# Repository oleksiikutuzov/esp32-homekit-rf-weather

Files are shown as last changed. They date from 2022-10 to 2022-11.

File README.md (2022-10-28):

# esp32-homekit-rf-weather

   

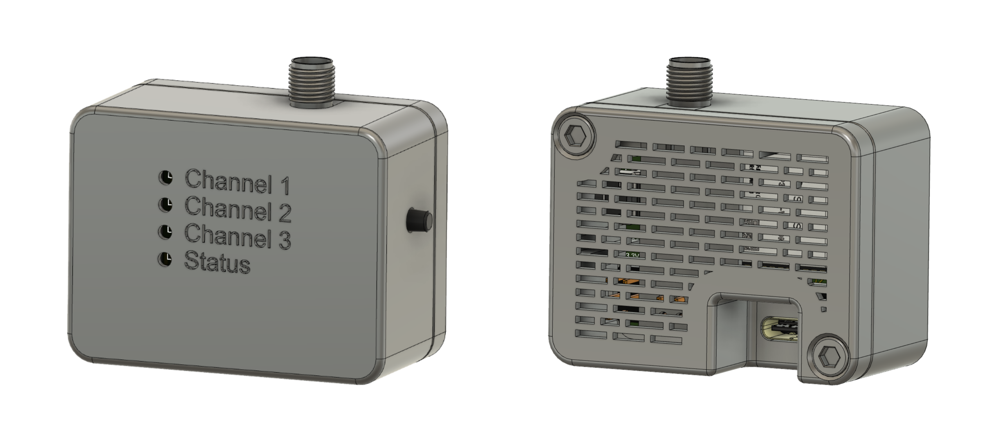
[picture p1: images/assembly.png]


The software is based on [HomeSpan](https://github.com/HomeSpan/HomeSpan) and [RTL_433_ESP](https://github.com/NorthernMan54/rtl_433_ESP) libraries.

> **Warning**
> Don't expect any warranties. I am just a hobbyist, not a professional. It works for me, but you take your own risk using it. I am not liable for any damage to your devices.

## Hardware requirements

1. [Custom PCB](https://github.com/oleksiikutuzov/esp32-homekit-rf-weather/tree/main/PCB) (BOM inside) from this project 
   
   or 
   
   any ESP32 Dev board e.g. [ESP32-DevKitC V4 board](https://docs.espressif.com/projects/esp-idf/en/latest/esp32/hw-reference/esp32/get-started-devkitc.html)
2. [E07-M1101D](https://manuals.plus/ebyte/e07-m1101d-sma-cc1101-433mhz-dip-wireless-module-manual#axzz7j0rVAbnv) 433 MHz Wireless module 

## Pinout

### Wireless module pins

If you are using a dev board, you will need to connect the wireless module to some specific pins of ESP32.

```
ESP32          Module
---------------------
GPIO18         SCK
GPIO19         MISO
GPIO23         MOSI
GPIO5          CS
GPIO22         GDO0
GPIO4          GDO2
```

### LEDs and control button pins

If you are using a dev board, you can utilize any pins you want or not use them at all. There is a control button to be able to reset the device, WIFI or HomeKit configuration. The status pin shows the current state of the device. More info on the status LED and control button is in [HomeSpan User](https://github.com/HomeSpan/HomeSpan/blob/master/docs/UserGuide.md) Guide](https://github.com/HomeSpan/HomeSpan/blob/master/docs/UserGuide.md). Three additional LEDs are blinking on the received signal on any of the channels. To redefine the pins for the dev board edit the following in the sketch:
```C++
#ifdef DEV_BOARD
	#define LED_CH1    13
	#define LED_CH2    21
	#define LED_CH3    17
	#define LED_STATUS 16
	#define BUTTON_PIN 15
```

## How to setup and install

1. Install [PlatformIO Core](https://platformio.org/install/cli) and [VSCode Plugin](https://docs.platformio.org/page/ide/vscode.html) (setup I am using and tested the instructions on) or [PlatformIO IDE](https://platformio.org/install/ide) with built-in Core.
2. Clone this repository
In the `platformio.ini` file set the default environment to `esp32_dev_board` or `esp32_custom_pcb` depending on the board you are using.
   ```
   [platformio]
   default_envs = esp32_custom_pcb
   ```
4. Build the firmware with a dedicated button in the PlatformIO extension or with the command 
   ```
   pio run
   ```
5. Upload the firmware with a dedicated button in the PlatformIO extension or with the command 
   ```
   pio run --target upload
   ```
6. You can monitor the serial output to check everything is working as intended with a dedicated button in the PlatformIO extension or with the command
   ```
   pio run --target monitor
   ```

## Custom Hardware

Custom PCB is designed for the project. Currently for regular ESP32 boards.

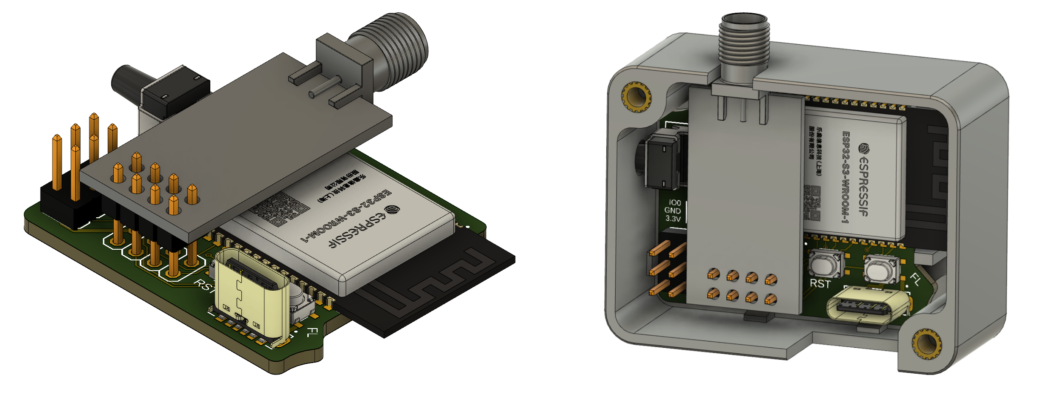
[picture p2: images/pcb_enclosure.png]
render


## Connect to HomeKit

1. Plug your LED Controller to power
2. The access point should start automatically. 
> **Note**
> Later you can manually enter configuration mode (More on [HomeSpan User Guide](https://github.com/HomeSpan/HomeSpan/blob/master/docs/UserGuide.md))
3. Go to WiFi settings on your iPhone/iPad and connect to the "HomeSpan-Setup" WiFi network
4. You will choose your WiFi network and set the setup code for the accessory
5. Go to your Home app and select "Add Accessory"
6. Select "More Options" and you should see your RF Weather Bridge there
## Settings and controls

When adding to HomeKit it will add the unsupported device called **RF Weather Bridge Settings** with device settings (3rd party apps like Eve support this and can be used for configuration). Available custom characteristics:
1. Toggle whether to blink the LEDs on receive
2. Showing the IP address the device is connected to
Set the number of channels, on which you want to receive (created an accessory for each channel). Can be set as 1 to 3
4. Toggle to reboot the device (to reload the device if you change the number of channels)

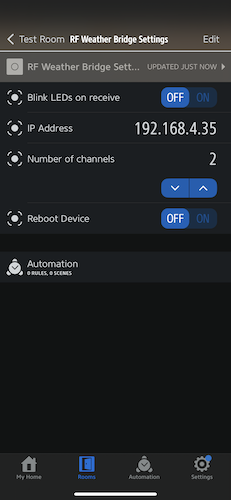
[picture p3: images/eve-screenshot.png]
eve screenshot


The device will throw a Status Fault in Eve app if there are no sensor updates for 5 minutes. 

Characteristics values are saved to NVS, so they will be restored if the device loses power. 

The web server update was implemented. You can flash binary at `http://[DEVICE IP]/update`.
There is a reboot link. Opening `http://[DEVICE IP]/reboot` will force the device to reboot. 

The device can also be controlled by the button on the board. More on [HomeSpan User Guide](https://github.com/HomeSpan/HomeSpan/blob/master/docs/UserGuide.md)

## TODO
### PCB:
- [ ] Add a USB-to-Serial converter to the board
- [ ] Make more space for flashing pin headers

## References and sources

- @HomeSpan for ESP32 HomeKit firmware [GitHub link](https://github.com/HomeSpan/HomeSpan)
- @NorthernMan54 for rtl_433_ESP library [GitHub link](https://github.com/NorthernMan54/rtl_433_ESP)

Although already forbidden by the sources and subsequent licensing, it is not allowed to use or distribute this software for commercial purposes.<br/><br/>

 

###### HomeKit Accessory Protocol (HAP) is Apple’s proprietary protocol that enables third-party accessories in the home (e.g., lights, thermostats and door locks) and Apple products to communicate with each other. HAP supports two transports, IP and Bluetooth LE. The information provided in the HomeKit Accessory Protocol Specification (Non-Commercial Version) describes how to implement HAP in an accessory that you create for non-commercial use and that will not be distributed or sold.

###### The HomeKit Accessory Protocol Specification (Non-Commercial Version) can be downloaded from the [HomeKit Apple Developer page.](https://developer.apple.com/homekit/)

###### Copyright © 2019 Apple Inc. All rights reserved.

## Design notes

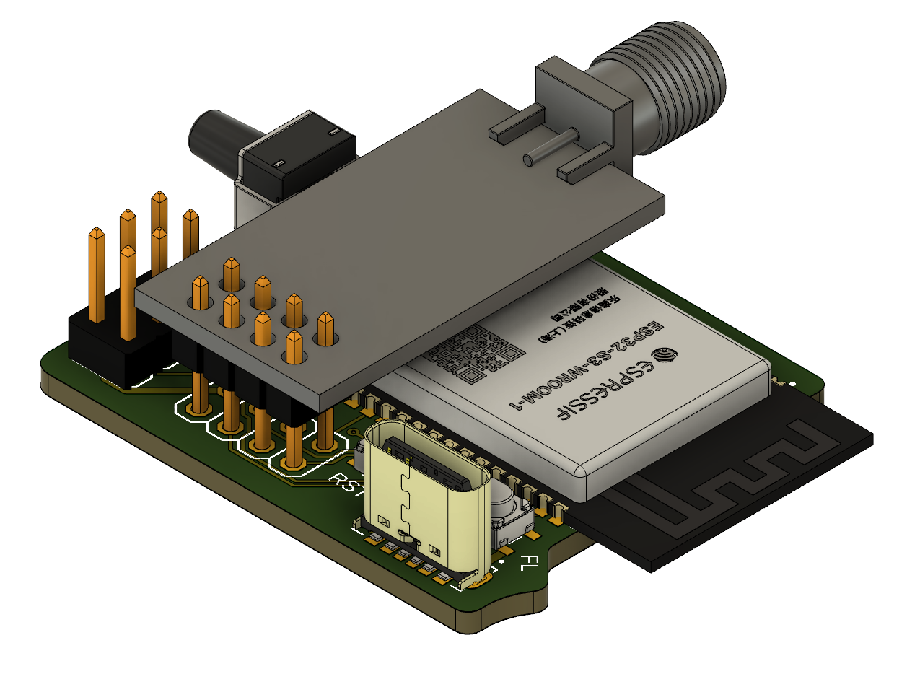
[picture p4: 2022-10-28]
images/pcb.png

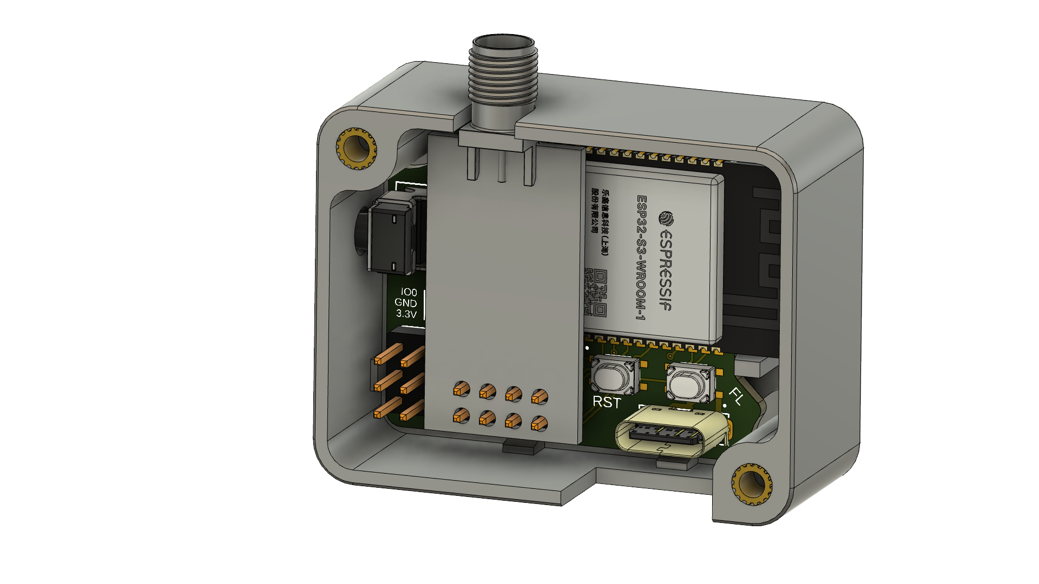
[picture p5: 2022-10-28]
images/enclosure_back.png

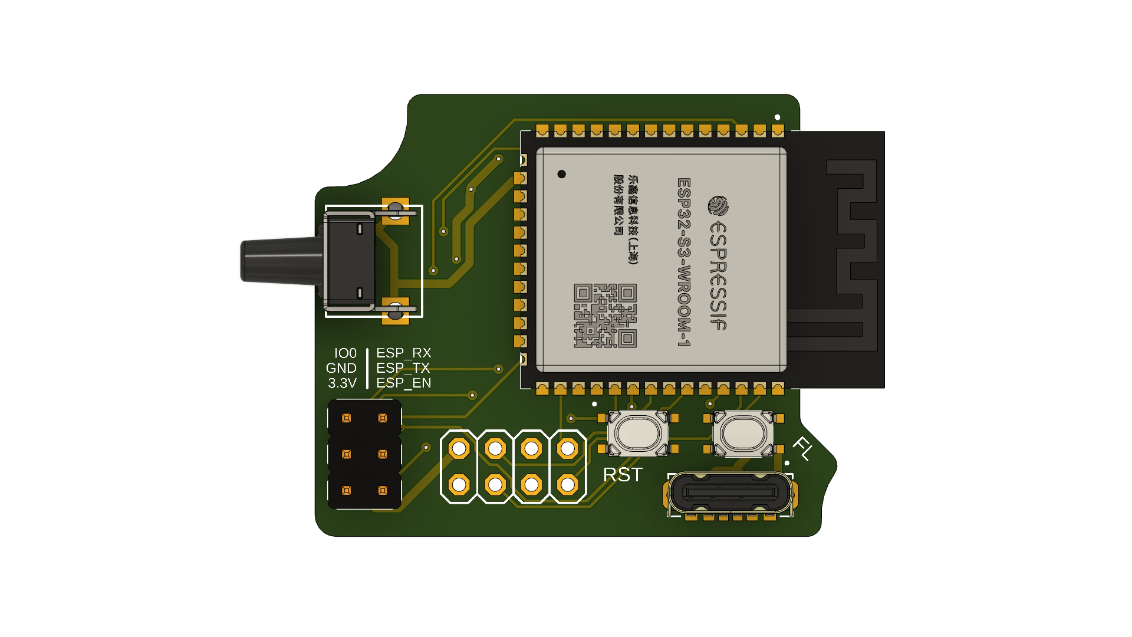
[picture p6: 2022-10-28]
PCB/PCB_TOP.png

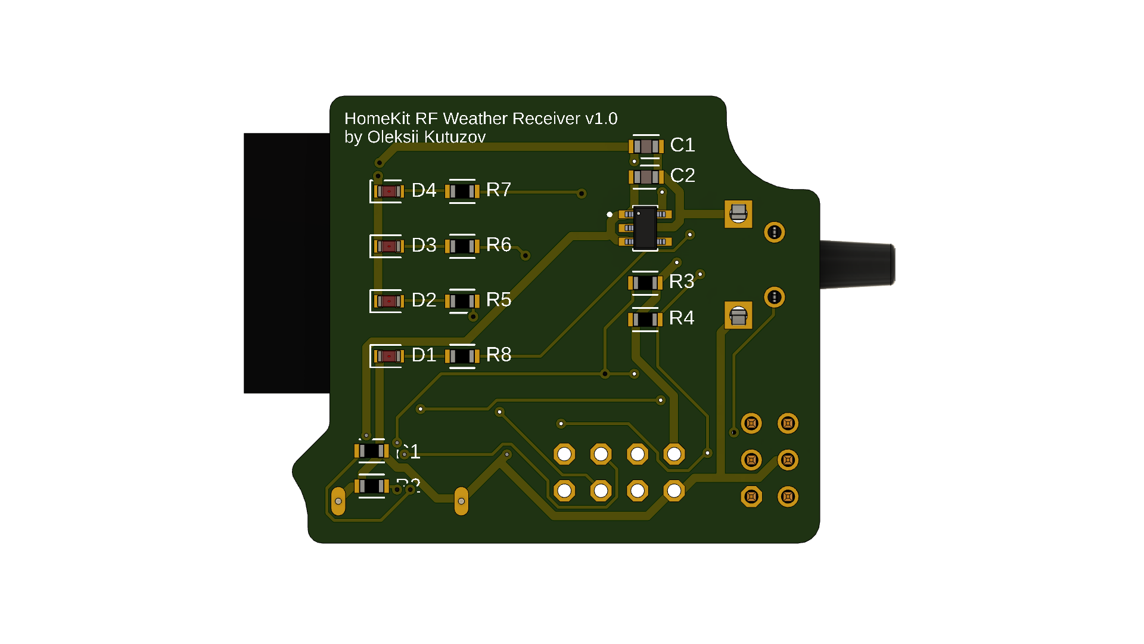
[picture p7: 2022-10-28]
PCB/PCB_BOTTOM.png

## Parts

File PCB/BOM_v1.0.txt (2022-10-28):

Partlist exported from /var/folders/tq/b2m_bkf11ld61j4hqq2g93cr0000gn/T/Neutron/ElectronFileOutput/48587/sch-562322ec-a9bd-47c2-8610-2d14c827d28f/Schematic v1.0 v14.sch at 28.10.22 16:01

Part Value                   Device                   Package                    Description                                                                 
C1   10uF                    C_CHIP-0603(1608-METRIC) CAPC1608X85                Capacitor - Generic                                                         
C2   10uF                    C_CHIP-0603(1608-METRIC) CAPC1608X85                Capacitor - Generic                                                         
D1   LED                     CHIP-FLAT-R_0603-0.80MM  LEDC1608X80N_FLAT-R                                                                                    
D2   LED                     CHIP-FLAT-R_0603-0.80MM  LEDC1608X80N_FLAT-R                                                                                    
D3   LED                     CHIP-FLAT-R_0603-0.80MM  LEDC1608X80N_FLAT-R                                                                                    
D4   LED                     CHIP-FLAT-R_0603-0.80MM  LEDC1608X80N_FLAT-R                                                                                    
J1   USB4125-GF-A_REVA       UJC-VP-3-SMT-TR          CUI_UJC-VP-3-SMT-TR        USB Receptacle                                                              
J3   ESPFLASH-2X3-2.54-PLAIN ESPFLASH-2X3-2.54-PLAIN  2X3-2.54-PLAIN             ESPFlash                                                                    
JP1  PINHD-2X4               PINHD-2X4                2X04                       PIN HEADER                                                                  
R1   5.1k                    R_CHIP-0603(1608-METRIC) RESC1608X60                Resistor Fixed - Generic                                                    
R2   5.1k                    R_CHIP-0603(1608-METRIC) RESC1608X60                Resistor Fixed - Generic                                                    
R3   4.7K                    R_CHIP-0603(1608-METRIC) RESC1608X60                Resistor Fixed - Generic                                                    
R4   4.7K                    R_CHIP-0603(1608-METRIC) RESC1608X60                Resistor Fixed - Generic                                                    
R5   430                     R_CHIP-0603(1608-METRIC) RESC1608X60                Resistor Fixed - Generic                                                    
R6   430                     R_CHIP-0603(1608-METRIC) RESC1608X60                Resistor Fixed - Generic                                                    
R7   430                     R_CHIP-0603(1608-METRIC) RESC1608X60                Resistor Fixed - Generic                                                    
R8   430                     R_CHIP-0603(1608-METRIC) RESC1608X60                Resistor Fixed - Generic                                                    
S1   SKRPACE010              SKRPACE010               SW_SKRPACE010              Switch Tactile N.O. SPST Button J-Bend 0.05A 16VDC 2.55N SMD Automotive T/R 
S2   SKRPACE010              SKRPACE010               SW_SKRPACE010              Switch Tactile N.O. SPST Button J-Bend 0.05A 16VDC 2.55N SMD Automotive T/R 
U$1  MOMENTARY-SWITCH        MOMENTARY-SWITCH         SWITCH-MOMENTARY                                                                                       
U1   AP2112K-3.3TRG1         AP2112K-3.3TRG1          SOT95P285X140-5N           AP2112 Series 0.6 A 3.3 V Fixed Output SMT LDO Linear Regulator - SOT23-5   
U2   ESP32-WROOM-32(8MB)     ESP32-WROOM-32(8MB)      MODULE_ESP32-WROOM-32(8MB) WIFI MODULE 64 MBITS SPI FLASH

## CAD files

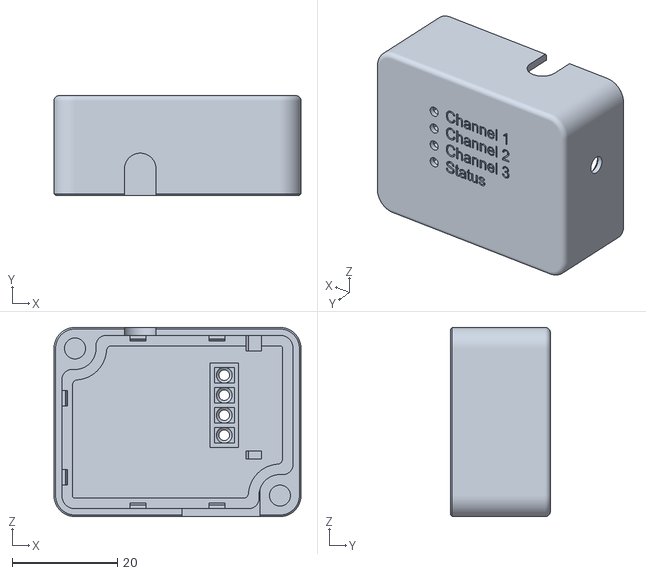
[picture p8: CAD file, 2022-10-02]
STL/Enclosure Front v27.stl
47.0 x 19.0 x 36.0

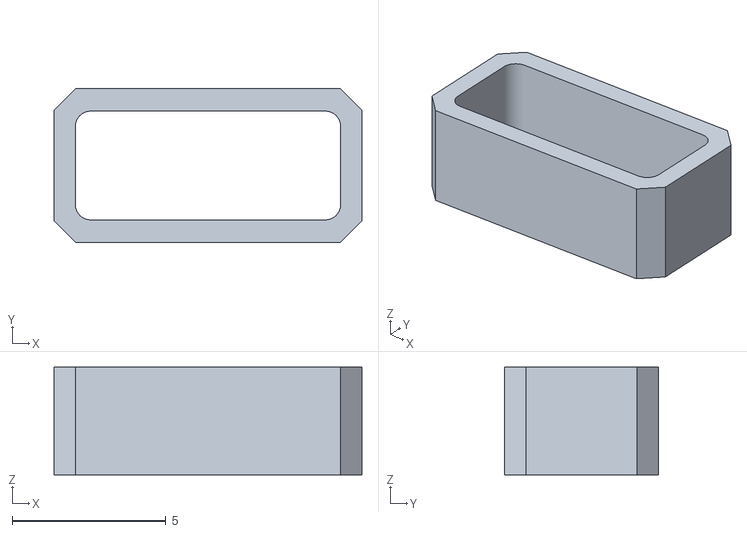
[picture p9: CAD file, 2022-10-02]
STL/Header Spacer v2.stl
10.0 x 5.00 x 3.50

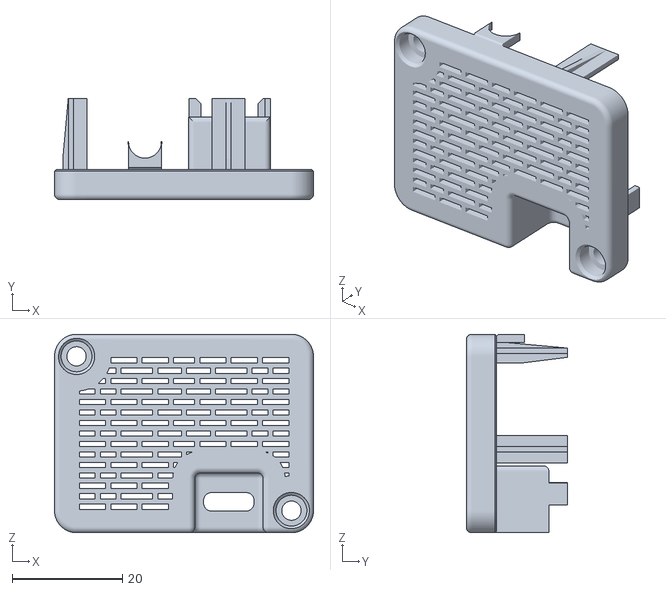
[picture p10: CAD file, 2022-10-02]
STL/Enclosure Back v22.stl
47.0 x 18.4 x 36.0

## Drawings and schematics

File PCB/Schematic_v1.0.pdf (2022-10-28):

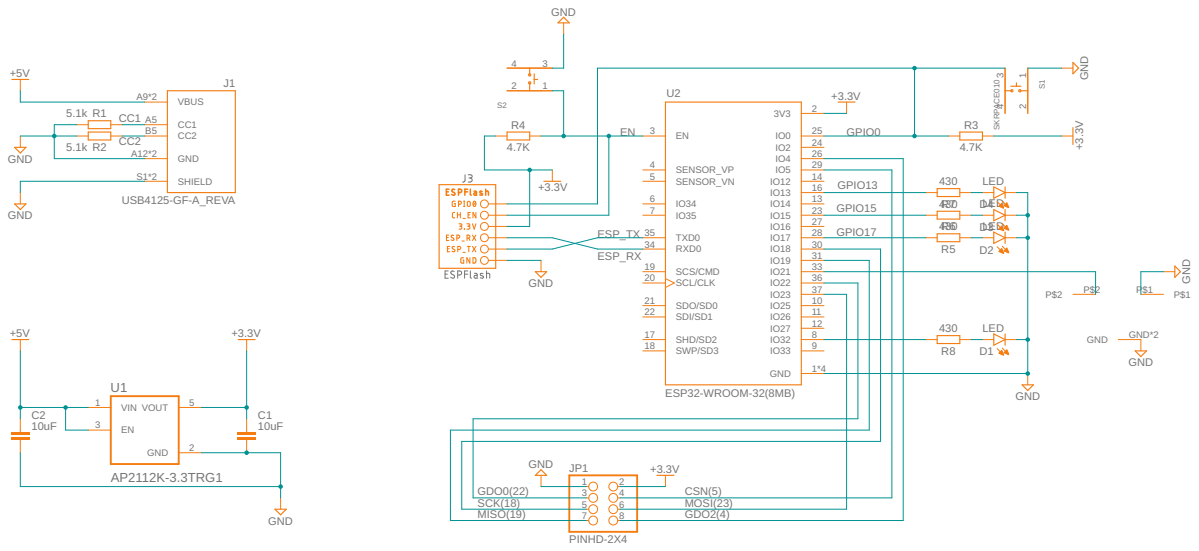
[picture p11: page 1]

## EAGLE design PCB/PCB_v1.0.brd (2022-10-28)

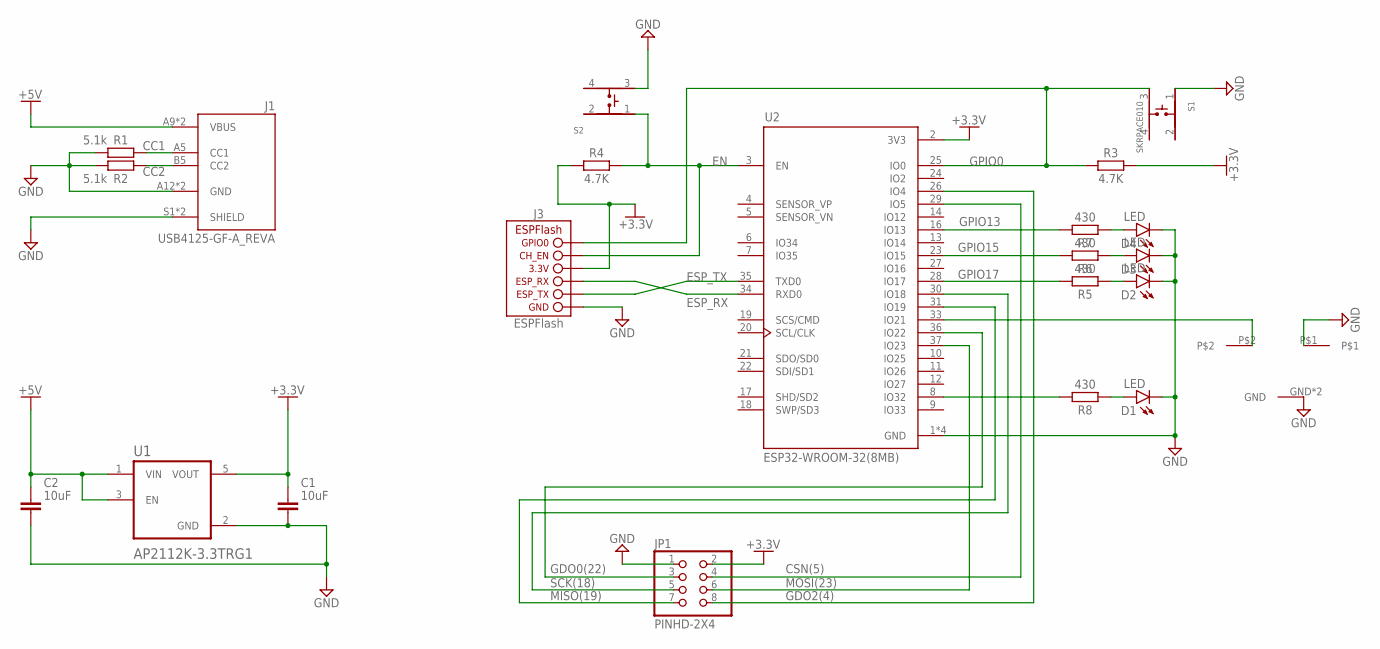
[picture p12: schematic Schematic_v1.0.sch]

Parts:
C1, C2: 10uF; CAPC1608X85
D1, D2, D3, D4: LED; LEDC1608X80N_FLAT-R
J1: USB4125-GF-A_REVA; CUI_UJC-VP-3-SMT-TR
J3: ESPFLASH-2X3-2.54-PLAIN; 2X3-2.54-PLAIN
JP1: PINHD-2X4; 2X04
R1, R2: 5.1k; RESC1608X60
R3, R4: 4.7K; RESC1608X60
R5, R6, R7, R8: 430; RESC1608X60
S1, S2: SKRPACE010; SW_SKRPACE010
U1: AP2112K-3.3TRG1; SOT95P285X140-5N
U2: ESP32-WROOM-32(8MB); MODULE_ESP32-WROOM-32(8MB)
U$1: MOMENTARY-SWITCH; SWITCH-MOMENTARY

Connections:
+3.3V: C1.1, J3.2 (3.3V), JP1.2, R3.2, R4.1, U1.5 (VOUT), U2.2 (3V3)
+5V: C2.1, J1.A9 (VBUS), J1.B9 (VBUS), U1.1 (VIN), U1.3 (EN)
CC1: J1.A5 (CC1), R1.1
CC2: J1.B5 (CC2), R2.1
CSN(5): JP1.4, U2.29 (IO5)
EN: J3.1 (CH_EN), R4.2, S2.1, U2.3 (EN)
ESP_RX: J3.5 (ESP_RX), U2.34 (RXD0)
ESP_TX: J3.3 (ESP_TX), U2.35 (TXD0)
GDO0(22): JP1.3, U2.36 (IO22)
GDO2(4): JP1.8, U2.26 (IO4)
GND: C1.2, C2.2, D1.C, D2.C, D3.C, D4.C, J1.A12 (GND), J1.B12 (GND), J1.S1 (SHIELD), J1.S2 (SHIELD), J3.4 (GND), JP1.1, R1.2, R2.2, S1.1, S2.3, U1.2 (GND), U2.1 (GND), U2.15 (GND), U2.38 (GND), U2.39 (GND), U$1.GND, U$1.GND_2 (GND), U$1.P$1
GPIO0: J3.6 (GPIO0), R3.1, S1.3, U2.25 (IO0)
GPIO13: R7.2, U2.16 (IO13)
GPIO15: R6.2, U2.23 (IO15)
GPIO17: R5.2, U2.28 (IO17)
MISO(19): JP1.7, U2.31 (IO19)
MOSI(23): JP1.6, U2.37 (IO23)
unnamed: D1.A, R8.1
unnamed: R8.2, U2.8 (IO32)
unnamed: D2.A, R5.1
unnamed: U2.33 (IO21), U$1.P$2
unnamed: D3.A, R6.1
unnamed: D4.A, R7.1
SCK(18): JP1.5, U2.30 (IO18)

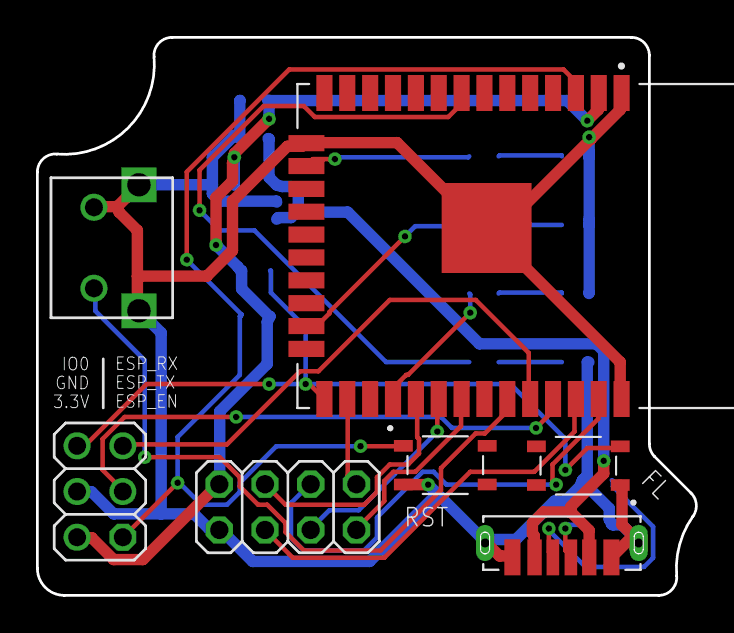
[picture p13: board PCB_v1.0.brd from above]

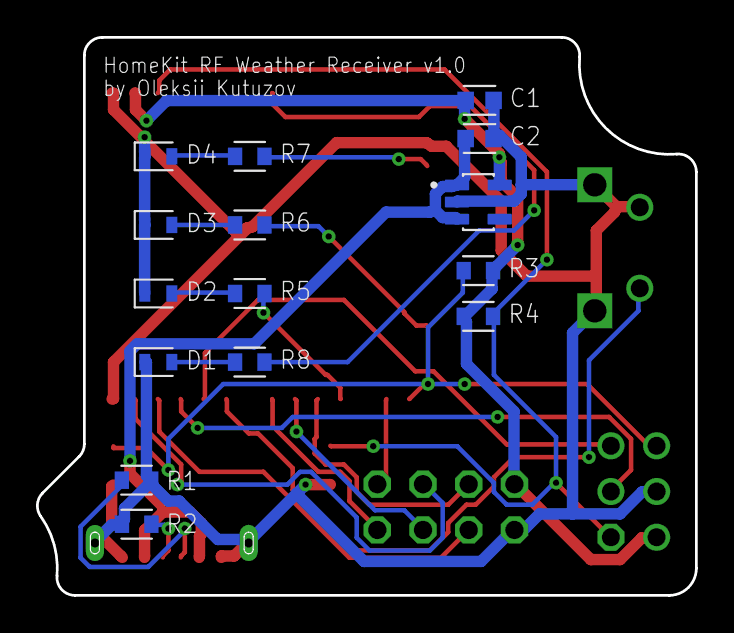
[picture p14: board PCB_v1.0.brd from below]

Board: 2 copper layers, 36.6 x 31.0 mm, 22 parts (15 on the bottom side), 24 nets.

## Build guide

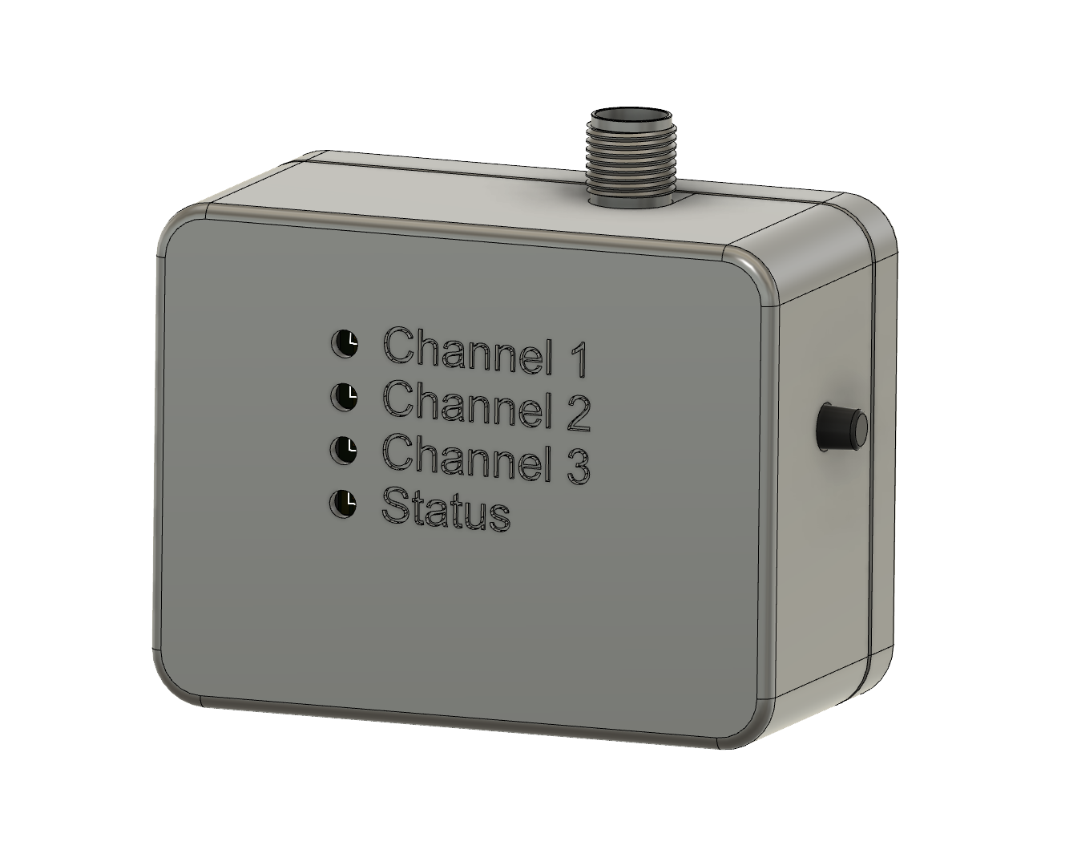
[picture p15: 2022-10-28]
images/assembly_front.png

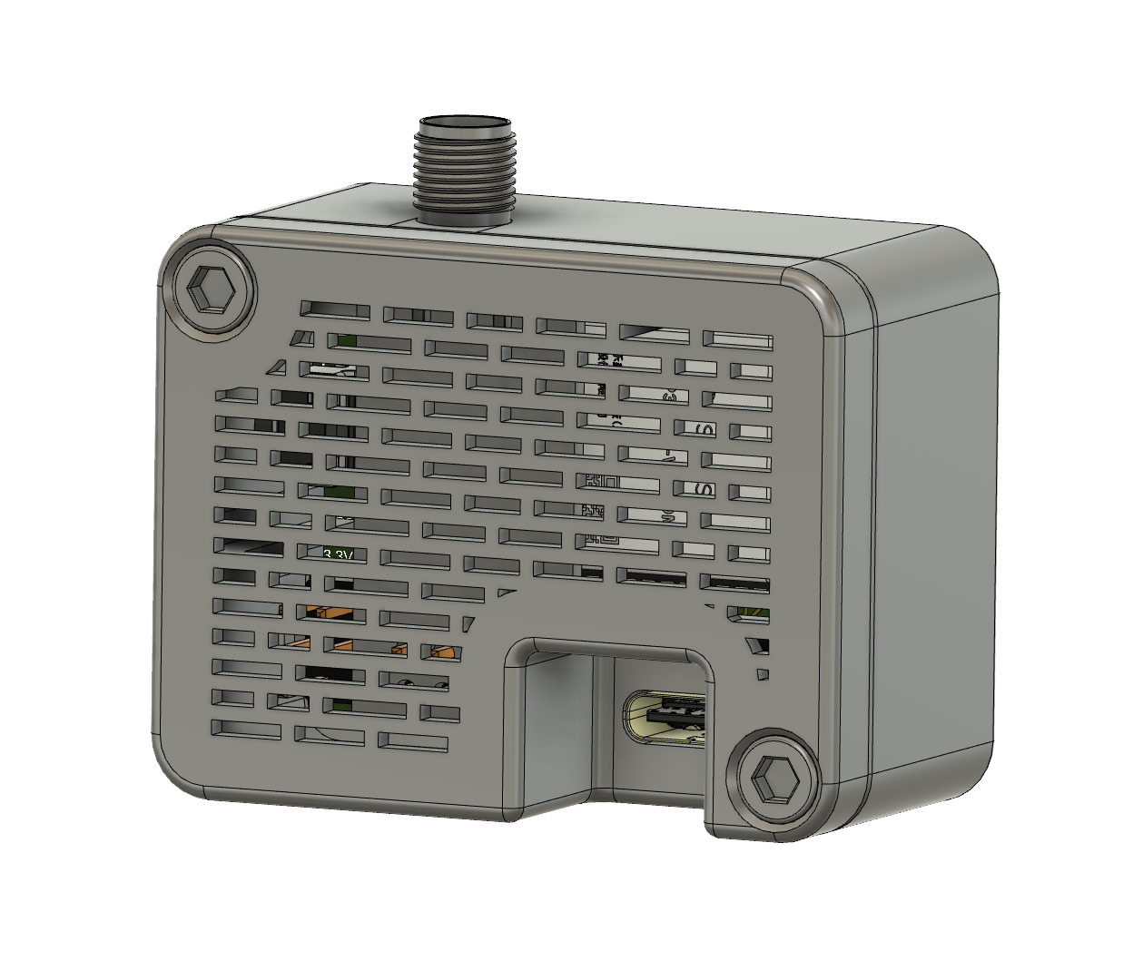
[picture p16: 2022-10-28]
images/assembly_back.png

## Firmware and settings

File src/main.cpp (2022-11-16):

/*********************************************************************************
 *  MIT License
 *
 *  Copyright (c) 2020 Gregg E. Berman
 *
 *  https://github.com/HomeSpan/HomeSpan
 *
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
 ********************************************************************************/

#define REQUIRED   VERSION(1, 7, 0)
#define FW_VERSION "1.2.0"

#include "DEV_Sensors.hpp"
#include <ElegantOTA.h>
#include <HomeSpan.h>
#include <WebServer.h>
#include <WiFiClient.h>

#include <ArduinoJson.h>
#include <ArduinoLog.h>
#include <rtl_433_ESP.h>

// *** Defines for RF receiver ***
#ifndef RF_MODULE_FREQUENCY
	#define RF_MODULE_FREQUENCY 433.92
#endif

#define JSON_MSG_BUFFER 512

#ifdef DEV_BOARD
	#define LED_CH1    13
	#define LED_CH2    21
	#define LED_CH3    17
	#define LED_STATUS 16
	#define BUTTON_PIN 15
#else
	#define LED_CH1    13
	#define LED_CH2    15
	#define LED_CH3    17
	#define LED_STATUS 32
	#define BUTTON_PIN 21
#endif

void logJson(JsonObject &jsondata);
void blinkLed(int pin);
void setupWeb();
void statusUpdate(HS_STATUS status);

char messageBuffer[JSON_MSG_BUFFER];

WebServer server(80);

char sNumber[18] = "11:11:11:11:11:11";

DEV_Settings *SETTINGS;

int                    led_pin[3] = {LED_CH1, LED_CH2, LED_CH3};
DEV_TemperatureSensor *TEMP_SENSORS[3];
DEV_HumiditySensor    *HUM_SENSORS[3];

void rtl_433_Callback(char *message) {
	DynamicJsonBuffer jsonBuffer2(JSON_MSG_BUFFER);
	JsonObject       &RFrtl_433_ESPdata = jsonBuffer2.parseObject(message);
	logJson(RFrtl_433_ESPdata);

	const char *model      = RFrtl_433_ESPdata["model"];
	int         id         = RFrtl_433_ESPdata["id"];
	int         channel    = RFrtl_433_ESPdata["channel"];
	bool        battery_ok = RFrtl_433_ESPdata["battery_ok"];
	String      battery    = (battery_ok == 1) ? "Ok" : "Low";
	float       temp       = RFrtl_433_ESPdata["temperature_C"];
	float       hum        = RFrtl_433_ESPdata["humidity"];

	// in this sensor channels are encoded as 0...2
	if (RFrtl_433_ESPdata["model"] == "LaCrosse-TX141THBv2") {
		channel++;
	}

	// get number of channels
	int  sensors = SETTINGS->num_sensors.getVal();
	bool led_on  = SETTINGS->leds_on.getVal();

	for (int i = 0; i < sensors; i++) {
		if (hum > 0 && temp > 0) {
			if (i + 1 == channel) {
				/********** block of 6 lines **********/
				LOG0("\n");
				LOG0("RX on channel " + String(i + 1));
				LOG0("\n");
				LOG0("Model: " + (String)model);
				LOG0("\n");
				LOG0("ID: " + (String)id);
				LOG0(" Battery: " + battery);
				LOG0("\n");
				LOG0("Temperature: " + (String)temp);
				LOG0("\n");
				LOG0("Humidity: " + (String)hum);
				LOG0("\n");
				/********** block of 6 lines **********/

				if (led_on == true) {
					blinkLed(led_pin[i]);
				}

				HUM_SENSORS[i]->last_received_val = 0;
				HUM_SENSORS[i]->hum->setVal(hum);
				HUM_SENSORS[i]->fault->setVal(0);
				TEMP_SENSORS[i]->temp->setVal(temp);
				if (battery_ok == true) {
					HUM_SENSORS[i]->battery->setVal(0);
				} else {
					HUM_SENSORS[i]->battery->setVal(1);
				}
			}
		}
	}
}

void logJson(JsonObject &jsondata) {
	char JSONmessageBuffer[jsondata.measureLength() + 1];
	jsondata.printTo(JSONmessageBuffer, sizeof(JSONmessageBuffer));
	// Log.notice(F("Received message : %s" CR), JSONmessageBuffer);
}

void setup() {

	Serial.begin(115200);

	Log.begin(LOG_LEVEL, &Serial);
	Log.notice(F(" " CR));
	Log.notice(F("****** setup ******" CR));
	rf.initReceiver(RF_MODULE_RECEIVER_GPIO, RF_MODULE_FREQUENCY);
	rf.setCallback(rtl_433_Callback, messageBuffer, JSON_MSG_BUFFER);
	//  ELECHOUSE_cc1101.SetRx(CC1101_FREQUENCY); // set Receive on
	rf.enableReceiver(RF_MODULE_RECEIVER_GPIO);
	Log.notice(F("****** setup complete ******" CR));

	Serial.print("Active firmware version: ");
	Serial.println(FW_VERSION);

	String     temp           = FW_VERSION;
	const char compile_date[] = __DATE__ " " __TIME__;
	char      *fw_ver         = new char[temp.length() + 30];
	strcpy(fw_ver, temp.c_str());
	strcat(fw_ver, " (");
	strcat(fw_ver, compile_date);
	strcat(fw_ver, ")");

	homeSpan.setControlPin(BUTTON_PIN);                        // Set button pin
	homeSpan.setStatusPin(LED_STATUS);                         // Set status led pin
	homeSpan.setLogLevel(1);                                   // set log level
	homeSpan.setPortNum(88);                                   // change port number for HomeSpan so we can use port 80 for the Web Server
	homeSpan.setStatusAutoOff(10);                             // turn off status led after 10 seconds of inactivity
	homeSpan.setWifiCallback(setupWeb);                        // need to start Web Server after WiFi is established
	homeSpan.reserveSocketConnections(3);                      // reserve 3 socket connections for Web Server
	homeSpan.enableWebLog(10, "pool.ntp.org", "UTC", "myLog"); // enable Web Log
	homeSpan.enableAutoStartAP();                              // enable auto start AP
	homeSpan.setSketchVersion(fw_ver);
	homeSpan.setStatusCallback(statusUpdate);

	homeSpan.begin(Category::Bridges, "HomeSpan RF Weather Bridge");

	new SpanAccessory();
	new Service::AccessoryInformation();
	new Characteristic::Identify();
	new Characteristic::FirmwareRevision(temp.c_str());

	new SpanAccessory();
	new Service::AccessoryInformation();
	new Characteristic::Identify();
	new Characteristic::Name("RF Weather Bridge Settings");
	SETTINGS = new DEV_Settings();

	// get number of channels
	int sensors = SETTINGS->num_sensors.getVal();

	for (int i = 0; i < 3; i++) {
		pinMode(led_pin[i], OUTPUT);
	}

	for (int i = 0; i < sensors; i++) {

		// blink led
		blinkLed(led_pin[i]);

		String channel_string     = "Channel ";
		String sensor_name_string = "Temperature and Humidity Sensor CH";

		char *channel_char     = new char[channel_string.length() + 2];
		char *sensor_name_char = new char[sensor_name_string.length() + 2];
		char  channel_num[2];

		sprintf(channel_num, "%d", i + 1);

		strcpy(channel_char, channel_string.c_str());
		strcpy(sensor_name_char, sensor_name_string.c_str());

		strcat(channel_char, channel_num);
		strcat(sensor_name_char, channel_num);

		new SpanAccessory();
		new Service::AccessoryInformation();
		new Characteristic::Identify();
		new Characteristic::Name(sensor_name_char);
		new Characteristic::Model(channel_char);
		TEMP_SENSORS[i] = new DEV_TemperatureSensor();
		HUM_SENSORS[i]  = new DEV_HumiditySensor();
	}
}

void loop() {
	homeSpan.poll();
	server.handleClient();
}

void setupWeb() {
	LOG0("Starting Air Sensor Hub...\n\n");

	server.on("/metrics", HTTP_GET, []() {
		// get number of channels
		int sensors = SETTINGS->num_sensors.getVal();

		float  temps[3];
		float  hums[3];
		String temp_metrics[3];
		String hum_metrics[3];
		String received_metrics[3];

		for (int i = 0; i < sensors; i++) {
			temps[i] = TEMP_SENSORS[i]->temp->getVal<float>();
			hums[i]  = HUM_SENSORS[i]->hum->getVal<float>();
		}

		float  uptime       = esp_timer_get_time() / (6 * 10e6);
		float  heap         = esp_get_free_heap_size();
		String uptimeMetric = "# HELP uptime Sensor uptime\nhomekit_uptime{device=\"rf_bridge\",location=\"home\"} " + String(int(uptime));
		String heapMetric   = "# HELP heap Available heap memory\nhomekit_heap{device=\"rf_bridge\",location=\"home\"} " + String(int(heap));

		LOG1("\n");
		LOG1(uptimeMetric);
		LOG1("\n");
		LOG1(heapMetric);
		LOG1("\n");

		for (int i = 0; i < sensors; i++) {
			temp_metrics[i] = "# HELP temp Temperature\nhomekit_temperature{device=\"rf_bridge\",channel=\"" + String(i + 1) + "\",location=\"home\"} " + String(temps[i]);
			hum_metrics[i]  = "# HELP hum Relative Humidity\nhomekit_humidity{device=\"rf_bridge\",channel=\"" + String(i + 1) + "\",location=\"home\"} " + String(hums[i]);

			LOG1(temp_metrics[i]);
			LOG1("\n");
			LOG1(hum_metrics[i]);
			LOG1("\n");
		}

		if (sensors == 1) {
			server.send(200, "text/plain", uptimeMetric + "\n" + heapMetric + "\n" + temp_metrics[0] + "\n" + hum_metrics[0]);
		} else if (sensors == 2) {
			server.send(200, "text/plain", uptimeMetric + "\n" + heapMetric + "\n" + temp_metrics[0] + "\n" + hum_metrics[0] + "\n" + temp_metrics[1] + "\n" + hum_metrics[1] + "\n" + received_metrics[1]);
		} else if (sensors == 3) {
			server.send(200, "text/plain", uptimeMetric + "\n" + heapMetric + "\n" + temp_metrics[0] + "\n" + hum_metrics[0] + "\n" + temp_metrics[1] + "\n" + hum_metrics[1] + "\n" + received_metrics[1] + "\n" + temp_metrics[2] + "\n" + hum_metrics[2] + "\n" + received_metrics[2]);
		}
	});

	server.on("/reboot", HTTP_GET, []() {
		String content = "<html><body>Rebooting!  Will return to configuration "
		                 "page in 10 seconds.<br><br>";
		content += "<meta http-equiv = \"refresh\" content = \"10; url = /\" />";
		server.send(200, "text/html", content);

		ESP.restart();
	});

	SETTINGS->ip_address.setString(WiFi.localIP().toString().c_str());
	ElegantOTA.begin(&server); // Start ElegantOTA
	server.begin();
	Serial.println("HTTP server started");
} // setupWeb

void blinkLed(int pin) {

	digitalWrite(pin, HIGH);
	delay(100);
	digitalWrite(pin, LOW);
}

// create a callback function that simply prints the pre-defined short messages on the Serial Monitor whenever the HomeSpan status changes
void statusUpdate(HS_STATUS status) {
	Serial.printf("\n*** HOMESPAN STATUS CHANGE: %s\n", homeSpan.statusString(status));
}

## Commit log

2022-09-08 Add second sensor
2022-09-09 Fix channels enumeration for particular sensor
    [main.cpp]
2022-09-10 Add battery status characteristic
2022-09-15 Add LED blinks on receive
2022-09-15 Adjust names of devices
2022-09-16 Sort out negative values (errors)
    [main.cpp]
2022-10-02 Add characteristics for OTA, number of devices, IP
2022-10-02 Reorganize code, dynamic switch number of channels
2022-10-02 Upload hardware files
    [Enclosure Back v22.stl, Enclosure Front v27.stl, Header Spacer v2.stl]
2022-10-02 Switch to custom Service for settings
2022-10-02 Fix to prometheus metrics export
    [main.cpp]
2022-10-03 Add pin numbers for pcb
2022-10-03 Separate build for pcb
2022-10-28 Update resources
    [PCB_v1.0.brd, Schematic_v1.0.sch]
2022-10-28 Add BOM
